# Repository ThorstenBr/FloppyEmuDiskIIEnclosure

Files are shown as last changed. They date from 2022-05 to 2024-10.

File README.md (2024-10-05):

# FloppyEmu Disk II Enclosure
This project contains OpenSCAD files, STL files, stickers and KiCad PCB to create a 3D-printed custom enclosure for the [Big Mess of Wires - FloppyEmu](https://www.bigmessowires.com/floppy-emu/) - an SD-card based disk drive emulator for the Apple II computer. The custom enclosure is a look-alike of the historic "Disk II" drive, Apple's first and hugely successful original disk drive for the Apple II, introduced in 1978.

As a bonus, this project also contains a housing for the Floppy Emu DB-19 plug adapter - a separate little 3D-print to protect the adapter (see "Bonus" section below).

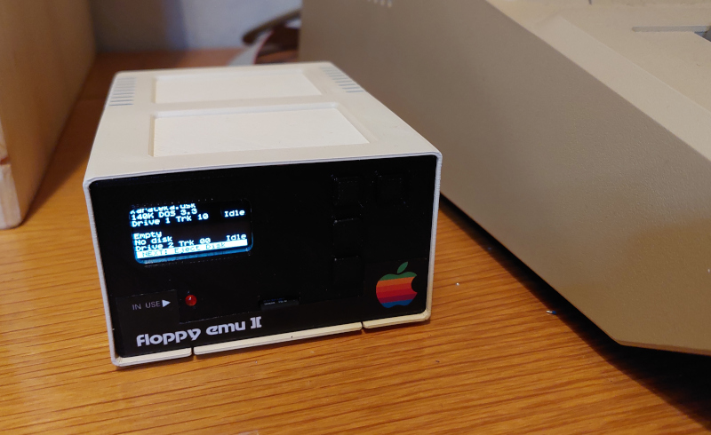
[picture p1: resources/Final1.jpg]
Final1

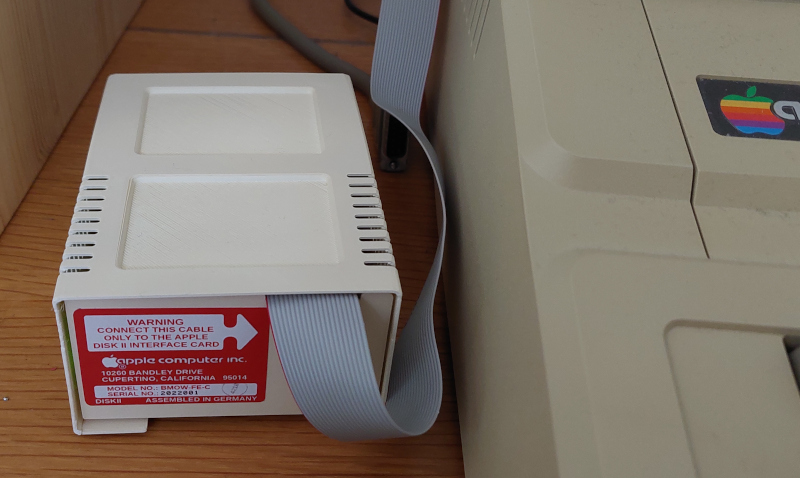
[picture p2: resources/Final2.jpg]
Final2


## Credits
The idea for this 3D-printing project was triggered by similar ideas to create Disk II-shaped custom enclosures for the FloppyEmu in the [AppleFritter](http://www.applefritter.com) forum - a forum for vintage Apple computer fans. See [this discussion thread](https://www.applefritter.com/content/yet-another-floppyemu-enclosure-3d-printing-approach) for more.

## License
This project is released under the "Creative Commons Attribution 4.0 International Public License". See [LICENSE](/LICENSE).

The Apple logo is a registered trademark of Apple Computer Inc. Any images and photos which may show the Disk II-FloppyEmu enclosure with an Apple logo were only given as an example of how you could decorate your Disk II-FloppyEmu drive enclosure for your personal use, to match the retro look of your wonderful original Apple II computer. The 3D-printed Disk II FloppyEmu enclosure is not endorsed by Apple. This project does not grant you any rights or licenses to distribute any 3D-printed enclosures with an Apple logo.

## Design
The 3D design is done with OpenSCAD. All files are available in the [scad](/scad/) folder.

The OpenSCAD file provides an option to generate the enclosure in different sizes. The minimum scale to fit the FloppyEmu PCB is 0.6 (= 60% of the original Disk II enclosure size). Currently, this reduced size is the only variant which is tested. The photos of the enclosure also show this reduced variant. Larger sizes will still require some tweaking in the SCAD files. The full-sized variant will be supported in the future (wait for it...).
You can also choose whether to use one LED (status LED only), or two LEDs (status + power LED). One LED is the default.

You can also find a ready-to-use STL files in the [stl](/stl/) folder. These STL files apply to the tested variant (60% of the original, one LED).

3D-Design2
3D-Design4
3D-Design3

## Button Panel
You will need a button panel, so you can control FloppyEmu from the front.
You can build the panel manually using a perfboard or order a printed circuit board (from JLCPCB etc).

The [pcb](/pcb/) folder contains all Gerber files required for a PCB order:

PCB
PCB

Alternatively, use a perfboard to solder the push buttons manually. It's only 4 buttons and a connector (and maybe the resistor for the status LED):

ButtonPanel1
ButtonPanel2

Schematics and the KiCad project for the PCB are also stored in [pcb](/pcb/) folder:

ButtonPanel4

PCB

The button PCB is eventually screwed to the front panel (Note: the photo does not show the latest design. The PCB is now mounted with 4 screws, one in each corner - see newer PCB design above).

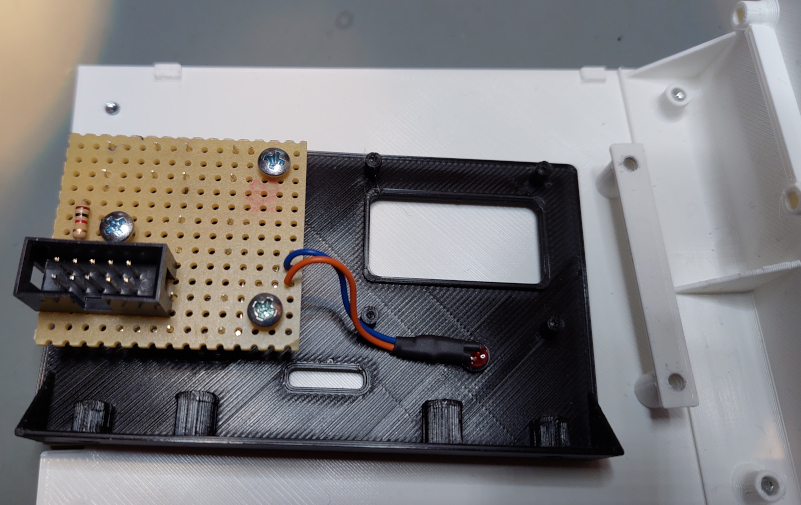
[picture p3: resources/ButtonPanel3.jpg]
ButtonPanel3


### Bill Of Materials

Here's what you need.

#### For the button panel:

- Manufactured PCB (i.e. upload the Gerber-Files to a PCB manufacturer, like JLCPCB). Alternatively use a [perfboard](https://en.wikipedia.org/wiki/Perfboard).
- 4x "micro switch push button 6x6x7mm" (ebay etc)
- 1x 3mm LED (red)
- 1x resistor (value depends on the type and intensity of your LED, usually 330 Ohm to 1KOhm)
- "2x5 box header" or, alternatively, "2x5 straight pin header"

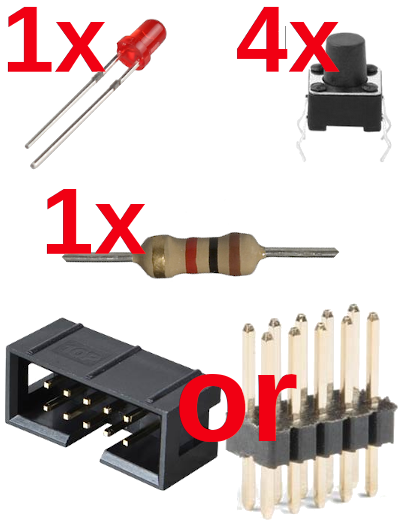
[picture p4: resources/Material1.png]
Material1


The four push buttons are very common and easy to obtain. They are similar as the onboard buttons of FloppyEmu. Except the PCB design is made for a through-hole type push buttons (not SMD buttons as on FloppyEmu). Switches with a 7mm peg are required to properly mount the printed button caps. Check on ebay searching for "micro switch push button 6x6x7mm". Your favourite electronics supplier should also have them (Germany: reichelt.de, TASTER 9303, Kurzhubtaster 6x6mm, 7,0mm).

#### For the button panel and LCD connector:
- You can use simple breadboard wires ("jumper wires") to connect FloppyEmu to the button panel and LCD. They are cheap and also come with a ribbon cable. The LCD and the button panel both require 7 wires each (since 3 pins of the button panel's pin header are unused).

- Alternatively, use "header plugs" with matching ribbon cable (2x5 for the button panel, 2x8 for the LCD) - as shown in the build photos. This is a slightly more expensive and complex solution. 

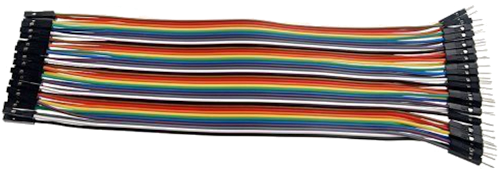
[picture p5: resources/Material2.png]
Material2


## Wiring FloppyEmu
The FloppyEmu PCB does not provide convenient pins or solder pads to tap the button and LED status signals. However, it's still relatively easy to tap the required signals - as shown by these photos. The photos apply to the Revision C model of the BMOW FloppyEmu. For other revisions, better verify the wiring with a multimeter.

A single wire is enough for each push button is enough: all four push buttons, including the reset button, connect to common ground. The status LED, however, does not connect to ground: it's wired between the status output signal and +5V (via an appropriate resistor for the LED, of course). The only feasible place is to solder directly next to the LED. The status signal is on the right of the LED – as shown. Be careful when soldering – just touch the LED very briefly with the iron – otherwise the onboard LED will die.

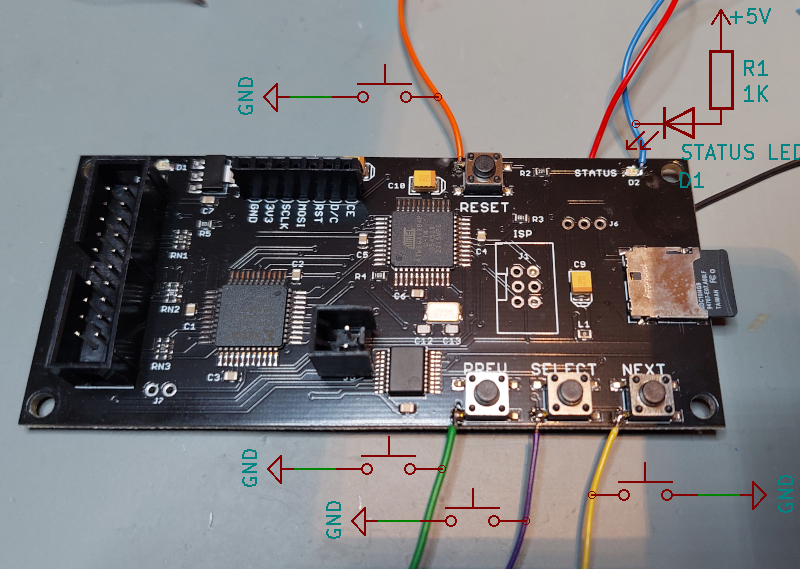
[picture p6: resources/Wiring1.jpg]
Wiring1


You can wire the ground lead (common for all push buttons) and the 5V (for the status LED) to the unpopulated debug connector in the middle of the FloppyEmu PCB. I soldered these two on the PCB’s bottom side, so they are almost “invisible” once the PCB is installed.

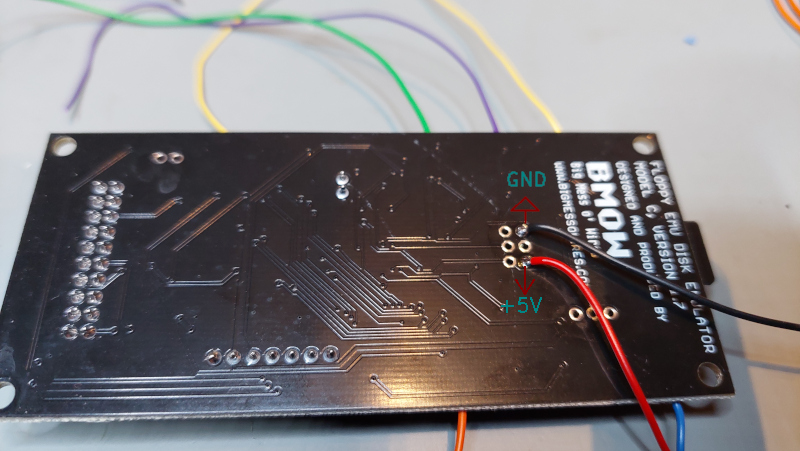
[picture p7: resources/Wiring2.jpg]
Wiring2


I suggest you solder all wires to a 2x5 pin header (or boxed header), so you can use a neat ribbon cable with plugs to connect the front button panel. The ribbon cable connects all four button signals, the status signal, ground and 5V – so three pins remain unused. If you wanted a power LED – just connect between ground and 5V (via a resistor, of course). See the schematics in the [pcb](/pcb) folder for a suggested pin assignment of the pin header/ribbon cable.

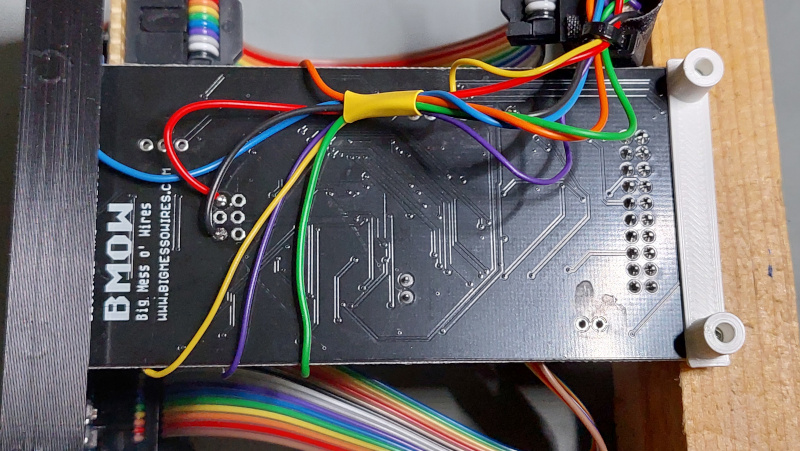
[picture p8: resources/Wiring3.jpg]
Wiring3


## 3D Print
3D printing is straight forward. The models should be printed with their flat side facing downwards.

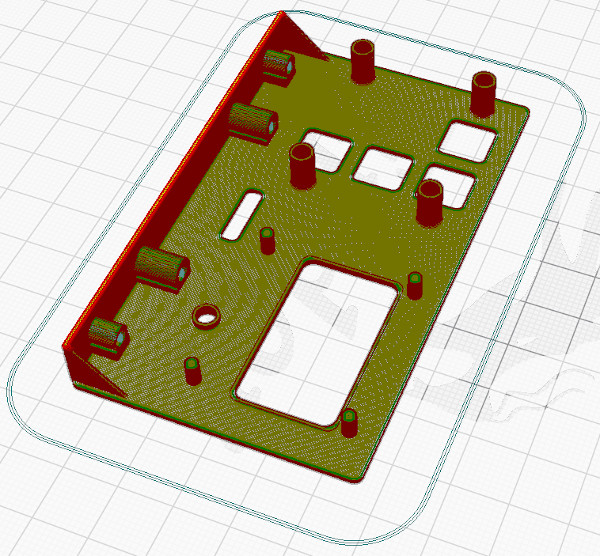
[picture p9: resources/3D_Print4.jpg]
3DPrint4


Preferably use white or light gray filament for the top shell, base plate, and for the rear panel. Use black filament for the front panel and the buttons.

The models are optimized to reduce 3D "supports", however, the top shell and the front panel still need "supports" to be enabled when printing.

The buttons should be printed without supports. Two brackets are also printed: a bracket for the PCB (feet to tbe attached to the PCB rear). And a bracket for the cable strain-relief (cable can be attached to a mount at the top/rear of the shell).

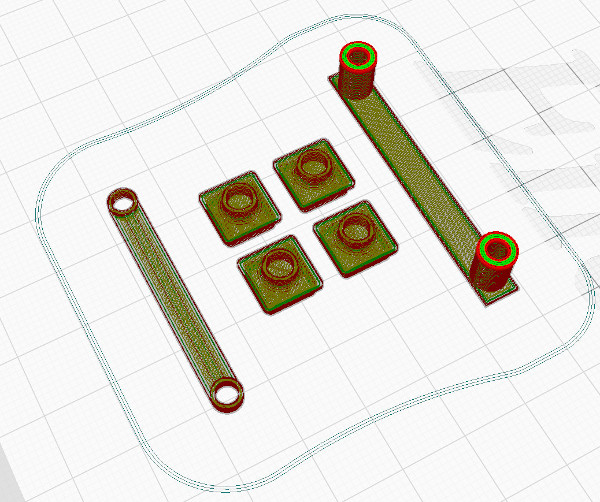
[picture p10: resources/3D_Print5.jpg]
3DPrint5


The large grooves on the top shell do require supports though - since this model should be printed upside down:

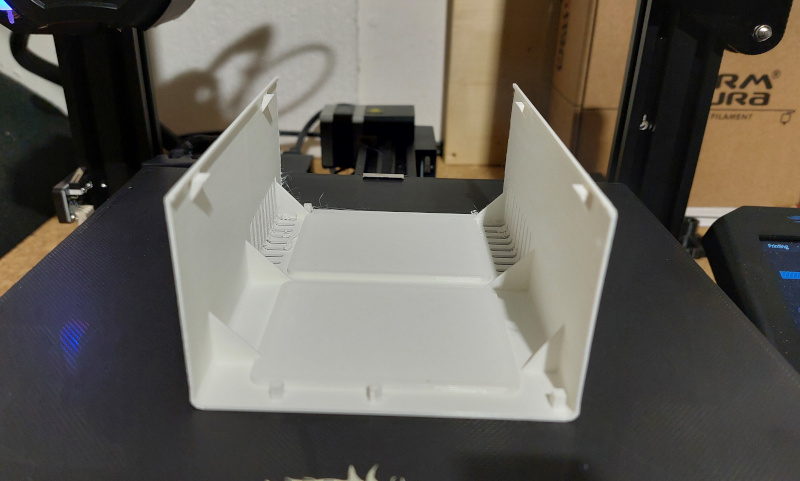
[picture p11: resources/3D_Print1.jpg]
3DPrint1


Carefully remove the printed "supports" to reveal the top grooves:

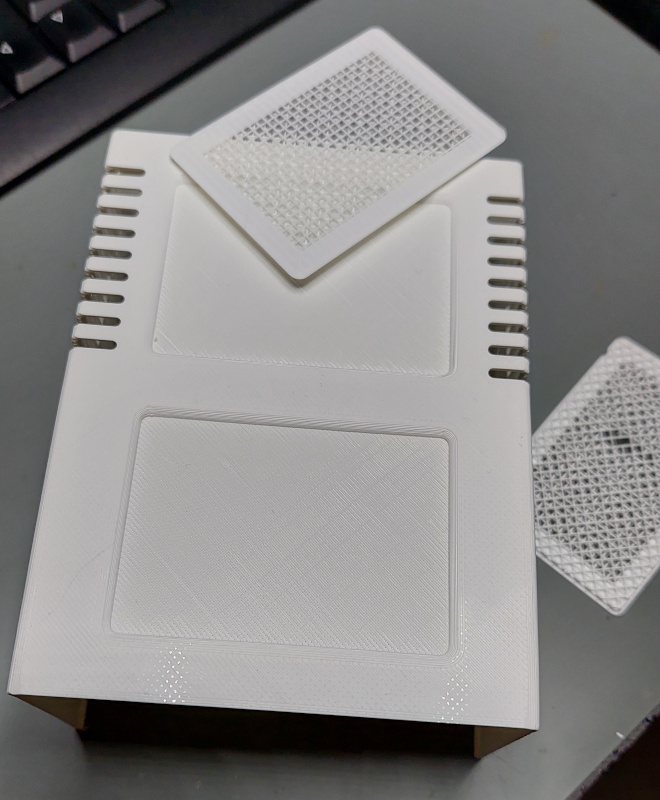
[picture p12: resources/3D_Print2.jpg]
3DPrint2


### Print Duration
The top shell takes about 7 hours to print on an Ender 3v2.
The front and rear panel require about 1:30 hours.
The buttons and mounting brackets require about 30 minutes.

## Assembly

### Shell
The top shell and the base plate should be glued together. Make sure to completely cover the seam between these two elements, since these two parts were split for easier 3D printing, and the original Disk II does have different seams. Smoothing these seams (before applying beige "Apple II"-like paint - I used spray-paint) comepletely hides the seam. Glueing these two parts also provides extra strength: there should be no more wobble or flexing once the two parts are glued.

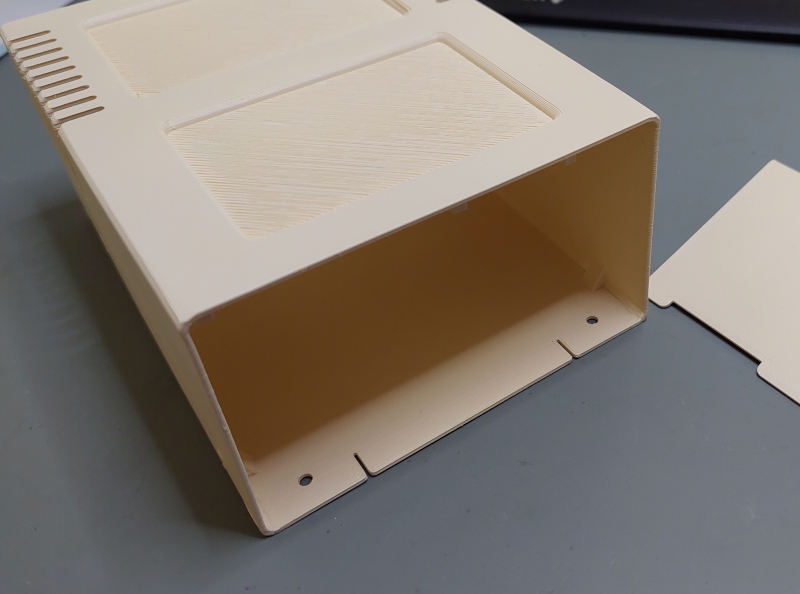
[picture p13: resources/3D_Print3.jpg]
3DPrint3


### Front Panel
First, the PCB is directly attached to the front panel with two screws.
The rear of the PCB is screwed to the printed mounting bracket ("PCB feet").
Then, attach the button PCB (perfboard of printed circuit board) with four screws to the front panel.
Make sure the four buttons are working fine
The push buttons only travel 0.25mm when depressed.
If the PCB was slightly warped or the buttons are soldered unevenly, slightly adjust the distance between the PCB and the front-panel.
Just unscrewing one of the four screws to release a bit of pressure may already be enough.

The LCD display is clipped into the front panel. The pegs should exactly fit to the original FloppyEmu LCD.
If necessary, use glue to prevent the LCD from slipping from the little pegs (this should normally not be necessary though, if you do not clip and remove the LCD from the front panel too often).

Use a ribbon cable to connect the LCD to the original connector on the FloppyEmu PCB (make sure to connect the cable with the correct orientation!).
Depending on the connector plugs, you may need to slightly bend the pins on the LCD, so they are angled 10-20° downward (may be necessary if the plug is too high and touches the top of the shell).

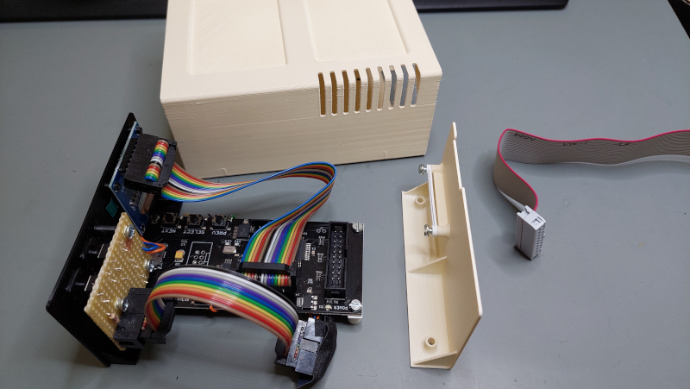
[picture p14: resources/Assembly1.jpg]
Assembly1


Eventually, when everything is connected, the whole assembly slides into the front of the 3D-printed shell.

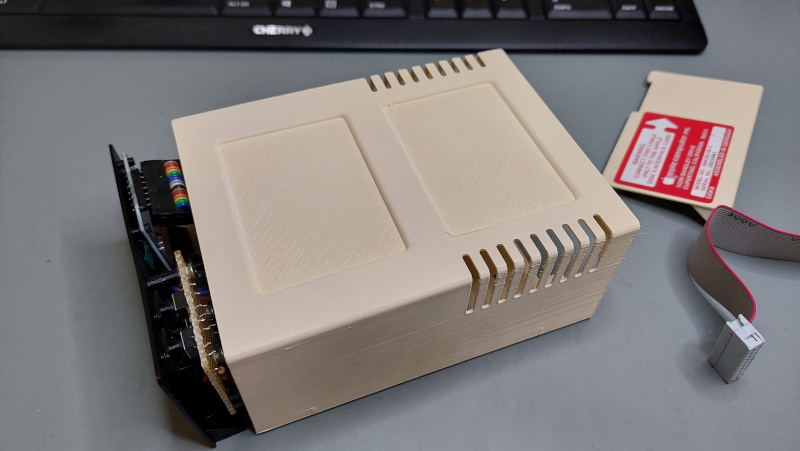
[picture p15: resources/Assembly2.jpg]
Assembly2


The front panel and the rear-bracket of the PCB are fixed to the base plate with screws from the bottom of the shell.

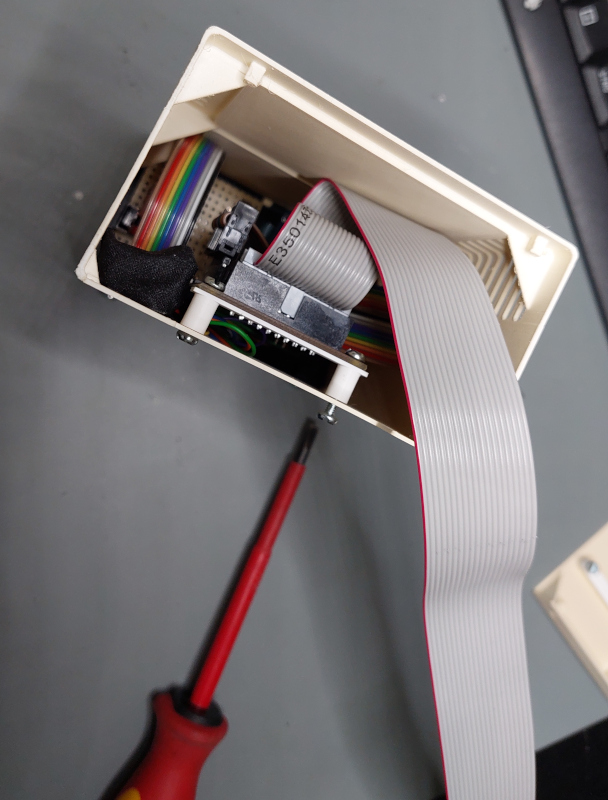
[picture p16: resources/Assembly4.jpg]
Assembly4


Once the PCB/front-panel is installed, connect the disk drive ribbon cable and use the printed cable bracket to attach the cable to the cable strain-relief at the top of the shell. This also guides the cable towards the cable slot in the rear-panel (photos above do not quite match: the cable strain-relief has since moved from the rear panel to the top of the shell).

Finally attach the rear panel with two screws from the bottom.

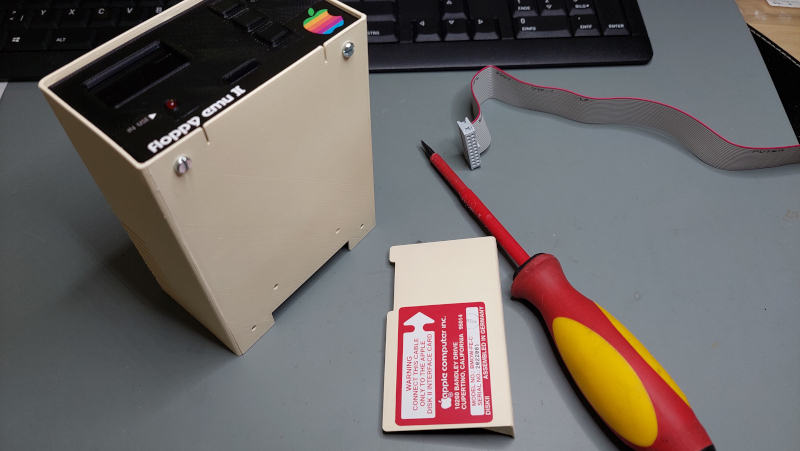
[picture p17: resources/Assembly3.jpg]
Assembly3


Almost done!

But remember: it's not complete... without rubber feet... :)

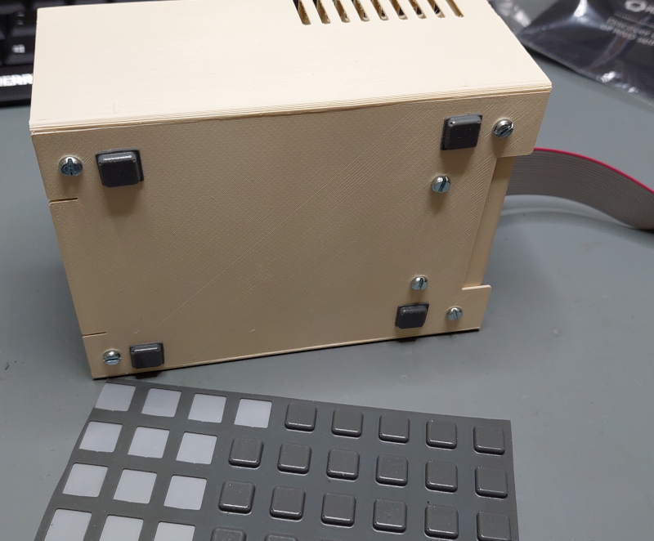
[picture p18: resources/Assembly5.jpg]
Assembly5


Done! :)

## Stickers
By the way, check the [sticker](/sticker/) folder for a collection of stickers to decorate your device.
Several variants of the rear sticker are provided.
The designs are also available as GIMP image files (.xcf), so you can adapt the text to your needs.

The stickers are now also available in high quality [here](/sticker/HighQuality). Many thanks to [khaibitgfx](https://www.applefritter.com/khaibitgfx)!

## Bonus: Floppy Emu DB-19 adapter housing

The Floppy Emu DB-19 adapter is provided as a bare PCB only. It is usually connected to the back of your Apple II and rarely touched. However, you should still be careful with the adapter since the pins carry the +5V rail and also the +/- 12V rails. Since Disk II cable has the +/-12V rails connected to pins which are directly next to disk control and read/write signals (TTL/5V logic). A shortcut between these pins could easily damage the disk controller, the Apple II, or FloppyEmu (or all of them):

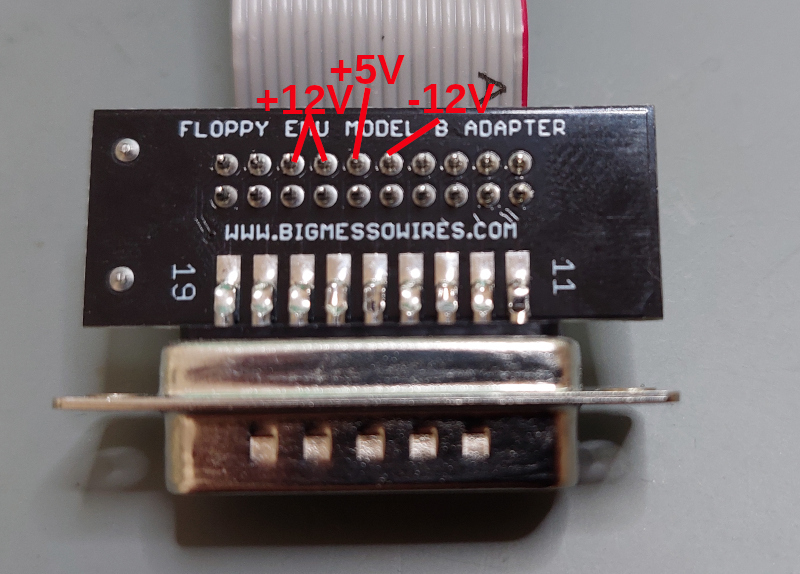
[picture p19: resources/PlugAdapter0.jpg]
PlugAdapter0


The 3D-printed plug adapter housing provides proper protection for the adapter. The adapter PCB slides right into the bottom part of the housing:

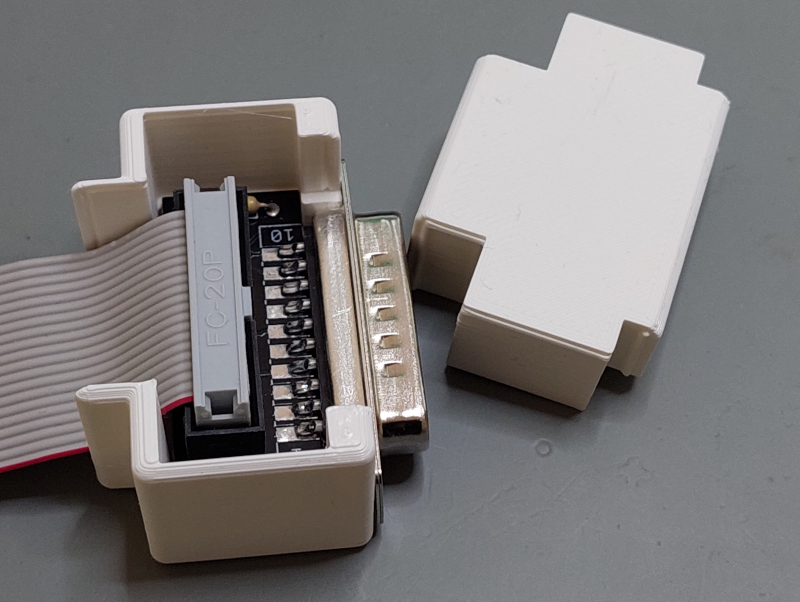
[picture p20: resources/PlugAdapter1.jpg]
PlugAdapter1


The top is printed with some notches, so it snaps right into place - and firmly holds the adapter PCB/plug:

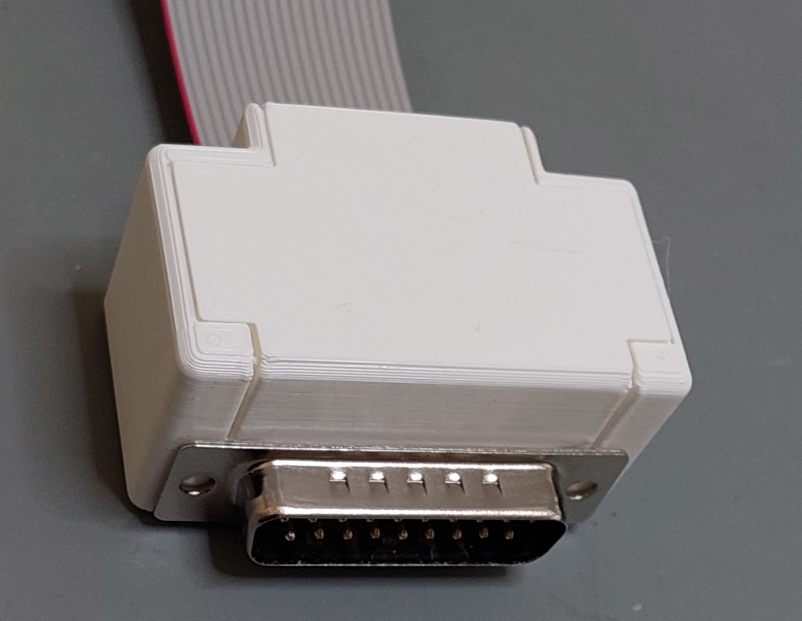
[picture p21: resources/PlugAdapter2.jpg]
PlugAdapter2

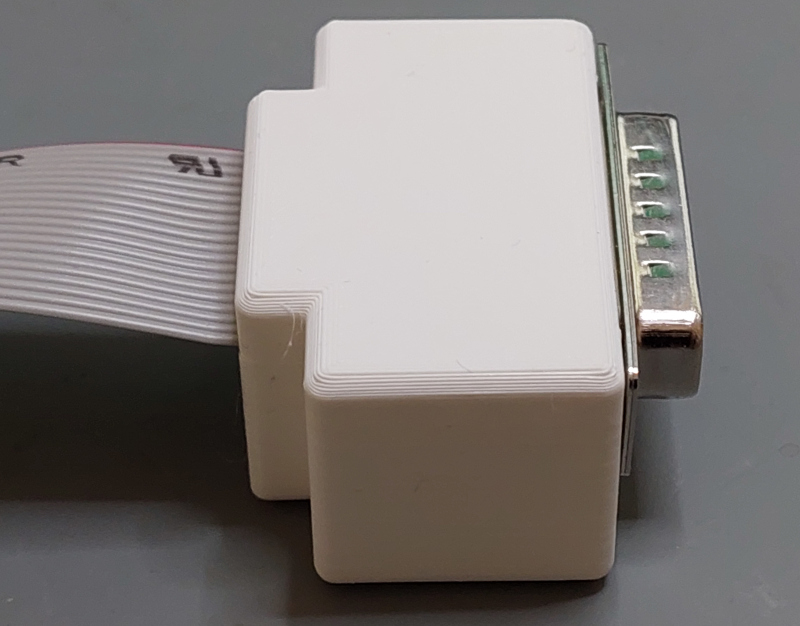
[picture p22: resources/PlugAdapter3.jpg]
PlugAdapter3


The result is a fairly bulky plug, but that's due to the clunky nature of the "_PCB-box header-header plug-ribbon cable_" assembly.

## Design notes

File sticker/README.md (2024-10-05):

These stickers are only provided as an example, of how you could decorate your 3D-printed enclosure.
You can adapt the stickers with GIMP, using the original XCF files, which allow to edit and adapt the text.

Also see the new high quality variant of the stickers [here](/sticker/HighQuality).

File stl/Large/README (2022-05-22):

This folder contains the full-sized variant of the FloppyEmu Disk II enclosure. It's at 1:1 scale of the original Disk II.
The full-sized box should be used with a 5mm LED and a custom 2.42" LCD display (128x64 pixels, SSD1309).
If you want to use the original 1.7" LCD of FloppyEmu then it's recommended to use the small (60%) box.

TBD: The 1:1 scaled design is currently untested. Hence, STL files are not yet provided. You could still generate the
full-scaled STL by using the SCAD files (OpenSCAD). However, the full-scaled variant of the design will most certainly
still require tweaking. Otherwise come back in a few months or so, to check on the status of the full-scaled variant...

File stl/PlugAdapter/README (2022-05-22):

Housing for Floppy Emu's DB-19 plug adapter.

Hints for printing:
* The models should be printed with their flat side facing downwards.
* Prints without supports.
* There are some bulky volumes to firmly hold the plug. I used Cura's stock infill setting (20%).
* The design printed fine with an Ender 3v2 printer, sliced with Ultimaker Cura using stock settings.
* Priting duration is about 2:10 hours (with Ender 3v2).

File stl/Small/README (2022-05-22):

This folder contains the small sized variant of the FloppyEmu Disk II enclosure. It's 60% of the size of the original Disk II.
It's just big enough to hold the FloppyEmu PCB.
The front panel holds the FloppyEmu's orginal 1.7" LCD, a single 3mm LED (drive status) and the button panel.

Hints for printing:
* The models should be printed with their flat side facing downwards.
* Preferably use white or light gray filament for the top shell, base plate, and for the rear panel.
* Use black filament for the front panel and the buttons.
* The models are optimized to reduce 3D "supports", however, the top shell and the front panel still need "supports" to be enabled when printing.
* The buttons/brackets and base-plate print without "supports".
* The infill setting doesn't matter (design does not contain any large filled volumes).
* The design printed fine with an Ender 3v2 printer, sliced with Ultimaker Cura using stock settings.

Printing Duration (estimates for an Ender 3v2):
* Top shell: about 7 hours.
* Front and rear panel: about 1:30 hours.
* Buttons and mounting brackets: about 30 minutes.

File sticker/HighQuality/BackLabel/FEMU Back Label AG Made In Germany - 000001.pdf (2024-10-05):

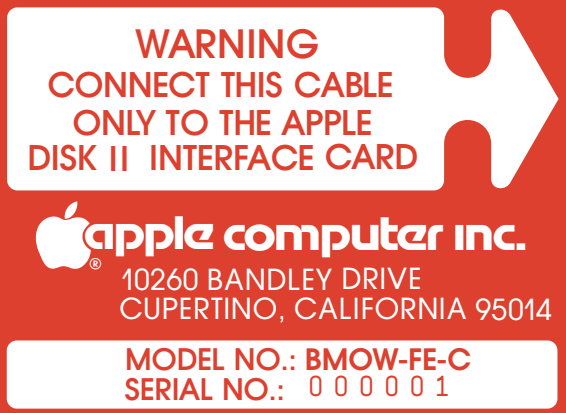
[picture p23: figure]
WARNING CABLE; ONLY DISK II; BANDLEY DRIVE CUPERTINO, CALIFORNIA; MODEL NO.: BMOW-FE-C SERIAL; CONNECT THIS TO THE APPLE INTERFACE CARD; apple computer inc.

MADE IN GERMANY

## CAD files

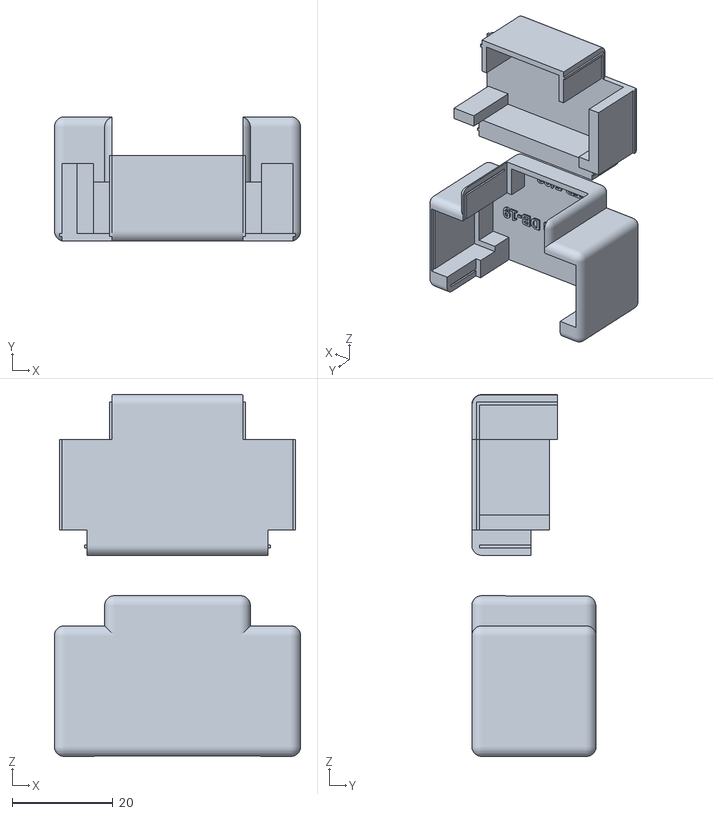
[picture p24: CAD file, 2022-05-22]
stl/PlugAdapter/plug_adapter.stl
49.0 x 24.8 x 72.0

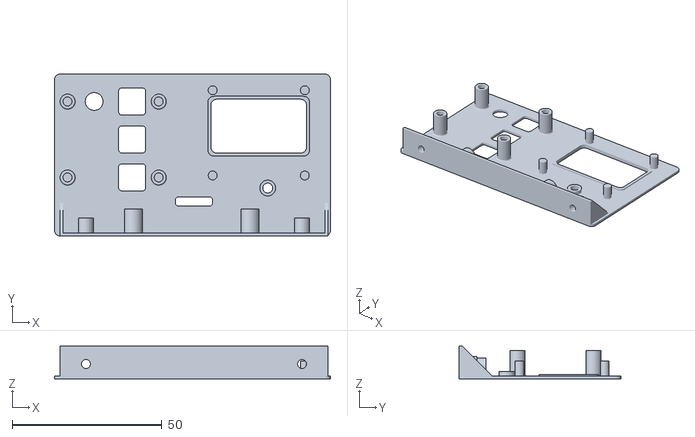
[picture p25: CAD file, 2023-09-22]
stl/Small/DiskII_FrontPanel_Small.stl
92.3 x 54.1 x 11.0

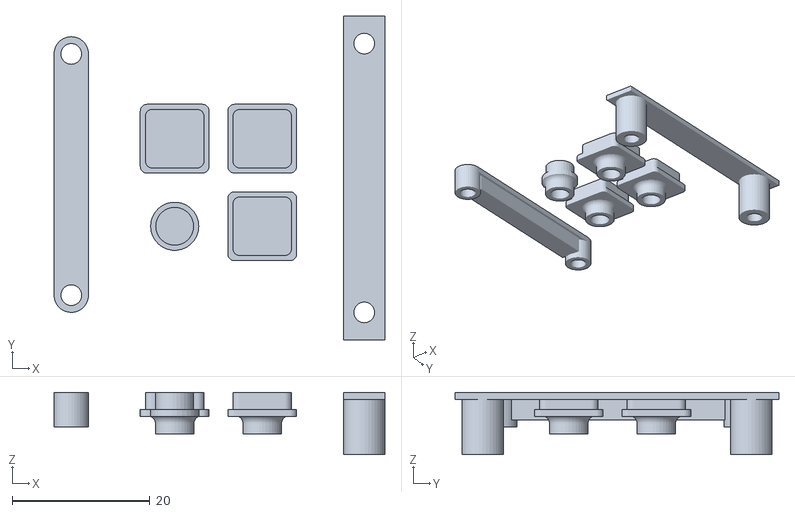
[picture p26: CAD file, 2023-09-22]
stl/Small/DiskII_ButtonsBrackets_Small.stl
48.0 x 47.0 x 9.00

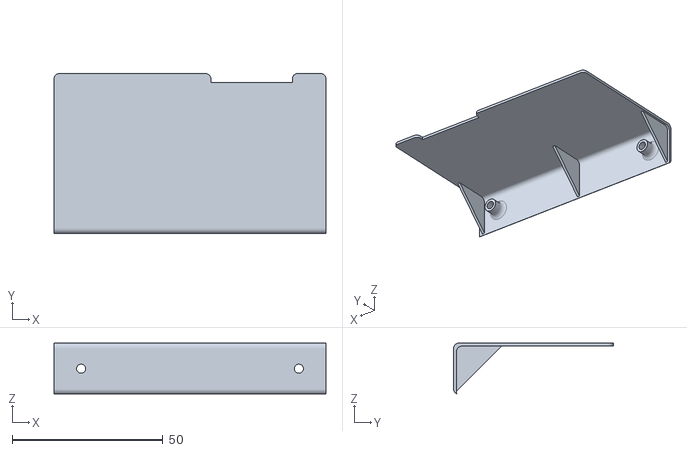
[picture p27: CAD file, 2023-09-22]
stl/Small/DiskII_RearPanel_Small.stl
90.3 x 53.1 x 16.9

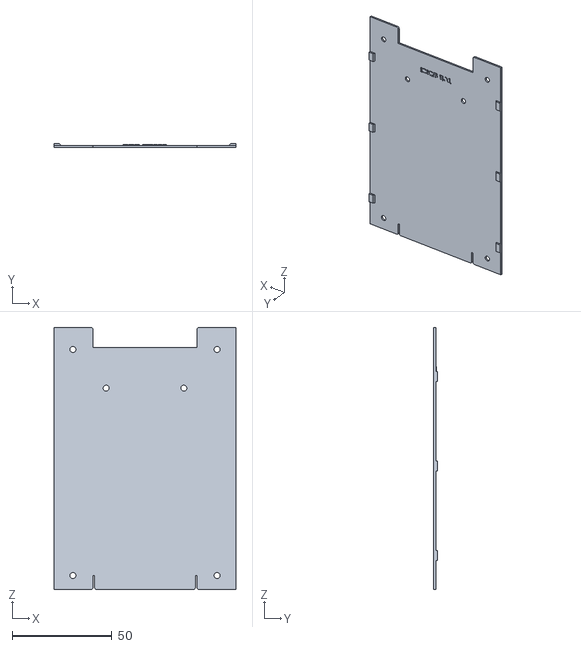
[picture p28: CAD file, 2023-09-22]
stl/Small/DiskII_BasePlate_Small.stl
91.2 x 2.00 x 131.4

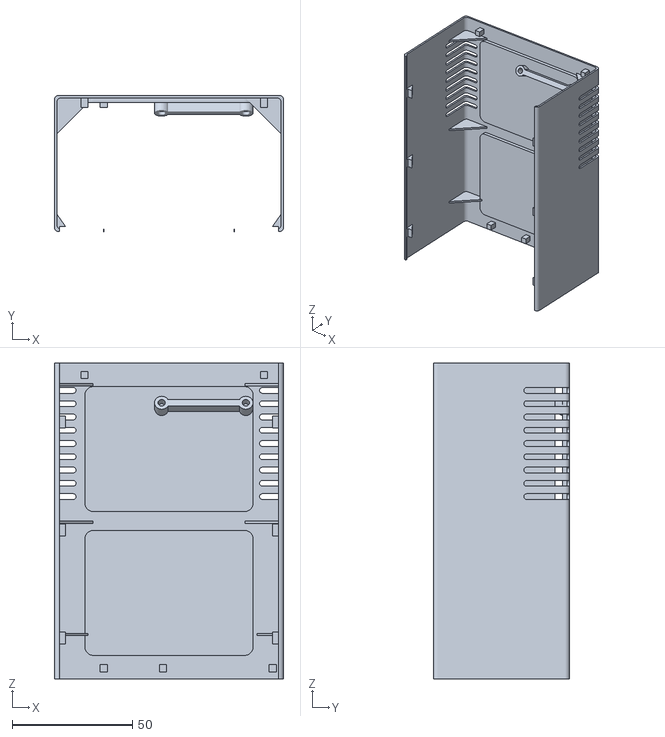
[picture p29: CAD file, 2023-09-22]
stl/Small/DiskII_TopShell_Small.stl
95.3 x 56.6 x 131.4

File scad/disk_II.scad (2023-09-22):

// Copyright 2022 Thorsten Brehm
// brehmt (at) gmail dot com

// Which part do you want to see/generate?
PART = "bottom"; // [button:Buttons and Brackets, bottom:Base board element, top:Top shell, rear:Rear panel, front:Front panel, test:--Test--, all:All elements, noRear:All except the rear panel, noFront:All except front panel, noBottom: All except base board, frontBottom: Front and base board only, topBottom: Top shell and base board only]

// Size of the LCD display?
LCD = "small"; // [small:Original 1.7inch display, large:Jumbo 2.42inch display]

// show FloppyEmu PCB?
PCB = "no"; // [no:No,yes:Yes]

// Size of the box: 1.0=original Disk II drive size, 0.6='baby box', just matching floppy EMU size
SCALING = 0.6; // [0.1 : 0.01 : 1]

// Which/how many LEDs?
LEDs = "one"; // [one:One / Activity LED,two:Both / Activity and Power LEDs]

/* [Internals] */
// Base board imprint
IMPRINT = "TCB 9/2023";  // 30

// Distance of the components (when showing 'exploded' elements)
SEPARATION = 30; // [0: 1: 100]

// Add cable strain-relief to top shell
STRAIN_RELIEF = "yes"; // [no:No,yes:Yes]

/* [Hidden] */
// Use prototype cutouts to save filament?
prototype = "no"; // [no:No,yes:Yes]

// Add 3D print supports
supports = "yes"; // [no:No,yes:Yes]

showPcb = PCB;
part = PART;
ComponentSeparation = SEPARATION;
ScalingFactor = SCALING;
LedCount = (LEDs == "two") ? 2 : 1;

include <components/main.scad>

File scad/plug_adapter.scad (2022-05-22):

// Copyright 2022 Thorsten Brehm
// brehmt (at) gmail dot com

// Enclosure for the Floppy Emu DB-19 Plug Adapter

// Which part do you want to see/generate?
PART = "topBottom"; // [topBottom: Both elements, bottom:Bottom element, top:Top element, test:--Test--, full:Full, mask:Show top mask, pcb:Show PCB, carving:Carved space]

/* [Hidden] */

// Adapter PCB
PcbWidthX = 46;
PcbHeightY = 2;
PcbDepthZ = 18;

// Box Header
BoxHeaderWidthX = 33.5;
BoxHeaderHeightY = 14;
BoxHeaderDepthZ = 11.5;

BoxHeaderPositonZ = PcbDepthZ-BoxHeaderDepthZ; // position from the front of the PCB

BoxHeaderPinHeightY = 2; // height of the pins on the PCB bottom side

// Cable
CableWidthX = 26;
CableHeightY = 1.0; // 1.5

CablePositionY = -CableHeightY/2;

// SUB-D Connector
SubDWidthX = 33;
SubDHeightY = 11.5;
SubDDepthZ = 13;

SubDPlateWidthX = 45;
SubDPlateHeightY = 13;
SubDPlateDepthZ = 1;

SubDPlatePositonZ = 5; // position from the front of the PCB

// rear
RearDepthZ = 6;

SKIN = 1.5;

SnapNotchX = 0.5;
SnapNotchY = 0.6;

// quality setting
QUALITY = "high";

include <components/baseLib.scad>

module imprint(x,y,z, txt, Font = "Liberation Sans:style=Bold")
{
	FontSize = 3;
	translate([x,y,z])
	rotate([270,0,0])
	{
		linear_extrude(height = 0.4) { text(txt, font = Font, size = FontSize, halign="center", valign="center"); }
	}
}

module makeFilamentSaver()
{
	translate([-BoxHeaderWidthX/2,0,0]) cube([BoxHeaderWidthX, PcbHeightY+BoxHeaderHeightY, BoxHeaderPositonZ]);
	translate([-PcbWidthX/2, PcbHeightY, SKIN*2]) cube([PcbWidthX-2*SKIN, BoxHeaderHeightY, PcbDepthZ-SKIN*2]);

	// cable
	translate([-(CableWidthX-2*SKIN)/2, -SubDHeightY/2, 0])
		cube([CableWidthX-2*SKIN, PcbHeightY+BoxHeaderHeightY+SubDHeightY/2, BoxHeaderPositonZ+BoxHeaderDepthZ+RearDepthZ+SKIN]);

	// Box header pins (below PCB)
	translate([-(PcbWidthX-2*SKIN)/2, -SubDHeightY/2, SKIN]) cube([PcbWidthX-2*SKIN, SubDHeightY/2, BoxHeaderDepthZ+BoxHeaderPositonZ-SKIN]);
}

module makePcb()
{
	// PCB
	translate([-PcbWidthX/2,0,0]) cube([PcbWidthX, PcbHeightY, PcbDepthZ]);

	// Box Header
	translate([-BoxHeaderWidthX/2, PcbHeightY, BoxHeaderPositonZ]) cube([BoxHeaderWidthX, BoxHeaderHeightY, BoxHeaderDepthZ]);

	// Box header pins (below PCB)
	translate([-BoxHeaderWidthX/2, -BoxHeaderPinHeightY, BoxHeaderPositonZ]) cube([BoxHeaderWidthX, BoxHeaderPinHeightY, BoxHeaderDepthZ]);

	// SUB-D connecor
	translate([-SubDWidthX/2, -SubDHeightY/2, -SubDDepthZ]) cube([SubDWidthX, SubDHeightY, SubDDepthZ+SKIN]);
	// SUB-D connector plate
	translate([-SubDPlateWidthX/2, -SubDPlateHeightY/2, -SubDPlatePositonZ-SubDPlateDepthZ]) cube([SubDPlateWidthX, SubDPlateHeightY, SubDPlateDepthZ]);

	// cable
	translate([-CableWidthX/2, CablePositionY, BoxHeaderPositonZ+BoxHeaderDepthZ]) cube([CableWidthX, CableHeightY, 20]);
}

module makeBlock()
{
	translate([-SKIN-PcbWidthX/2, -SKIN-SubDHeightY/2, -SubDPlatePositonZ])
		rcube(size=[2*SKIN + PcbWidthX, 2*SKIN + SubDHeightY/2+PcbHeightY+BoxHeaderHeightY, SKIN*2 + PcbDepthZ+SubDPlatePositonZ],
	              radius=[2,2,2], center=false);

	translate([-SKIN-CableWidthX/2, -SKIN-SubDHeightY/2, PcbDepthZ-1])
		rcube(size=[2*SKIN + CableWidthX, 2*SKIN + SubDHeightY/2+PcbHeightY+BoxHeaderHeightY, SKIN*2 +RearDepthZ+1],
	              radius=[2,2,2], center=false);
}

module makeThing()
{
	difference()
	{
		makeBlock();
		union()
		{
			makePcb();
			makeFilamentSaver();
		}
	}
	imprint(0, -SubDHeightY/2, PcbDepthZ/2, "Floppy Emu DB-19");
	imprint(0, -SubDHeightY/2, PcbDepthZ+RearDepthZ/2+SKIN, "TB 5/22");
}

module makeTopMask()
{
	// cable
	translate([-CableWidthX/2, CablePositionY+CableHeightY, BoxHeaderPositonZ+BoxHeaderDepthZ])
		cube([CableWidthX, SKIN+BoxHeaderHeightY-CablePositionY+PcbHeightY-CableHeightY, 20]);

	// PCB area
	translate([-PcbWidthX/2, PcbHeightY, 0])
		cube([PcbWidthX, SKIN+BoxHeaderHeightY, PcbDepthZ]);

	// subd
	translate([-(SubDWidthX+2*SKIN)/2, SubDHeightY/2, -SubDDepthZ])
		cube([SubDWidthX+2*SKIN, SKIN+PcbHeightY+BoxHeaderHeightY-SubDHeightY/2, SubDDepthZ]);

	// click notch (cable)
	translate([-CableWidthX/2-SnapNotchX, BoxHeaderHeightY+SKIN+0.5, PcbDepthZ])
		cube([CableWidthX+SnapNotchX*2, SnapNotchY, RearDepthZ+SKIN]);
	translate([-CableWidthX/2-SnapNotchX, CablePositionY+CableHeightY, PcbDepthZ+RearDepthZ+SKIN/2+0.15])
		cube([CableWidthX+SnapNotchX*2, BoxHeaderHeightY-CablePositionY+PcbHeightY-SKIN+0.5, SnapNotchY]);

	// click notch (PCB)
	translate([-PcbWidthX/2-SnapNotchX, BoxHeaderHeightY+SKIN+0.5, 0])
		cube([PcbWidthX+SnapNotchX*2, SnapNotchY, PcbDepthZ]);

	// click notch (subd)
	translate([-(SubDWidthX+2*SKIN+SnapNotchX*2)/2, SubDHeightY/2, -SubDPlatePositonZ+SKIN])
		cube([SubDWidthX+2*SKIN+SnapNotchX*2, PcbHeightY+BoxHeaderHeightY-SubDHeightY/2, SnapNotchY]);

}

module makeTop()
{
	intersection()
	{
		makeThing();
		makeTopMask();
	}
}

module makeBottom()
{
	difference()
	{
		makeThing();
		makeTopMask();
	}
}

module main()
{
	if (PART == "test")
	{
	}
	else
	if (PART == "top")
	{
		makeTop();
	}
	else
	if (PART == "bottom")
	{
		makeBottom();
	}
	else
	if (PART == "full") {
                 makeThing();
	}
	else
	if (PART == "mask")
	{
		makeTopMask();
	}
	else
	if (PART == "topBottom")
	{
		translate([0, PcbHeightY+BoxHeaderHeightY+SKIN, 40]) rotate([180,180,0]) makeTop();
		translate([0, SKIN+SubDHeightY/2, 0]) makeBottom();
	}
	else
	if (PART == "carving")
	{
		makePcb();
		makeFilamentSaver();
	}
	else
	if (PART == "pcb") {
		makePcb();
	}
	else
	{
		// nothing!
	}
}

main();

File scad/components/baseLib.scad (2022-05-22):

// Copyright 2022 Thorsten Brehm
// brehmt (at) gmail dot com

module torus(r1, r2)
{
    rotate_extrude(convexity = 10)
		translate([r2 + r1, 0, 0])
			circle(r=r2);
}

module round_cylinder(fillet, r, h)
{
	for(z=[fillet, h-fillet])
		torus(r-2*fillet, fillet, center=[0,0,z]);
	cylinder(r=r-fillet, h);
	translate([0,0,fillet]) cylinder(r=r, h=h-2*fillet);
}

// Make a rectangle with rounded corners of given radius.
// The maximum outer dimensions exactly match the given width/height.
module roundedCube(Width, Height, Depth, CornerRadius)
{
	$fn=36;
	union()
	{
		for (x=[0,Width-CornerRadius*2])
		for (y=[0,Height-CornerRadius*2])
			translate([x+CornerRadius, y+CornerRadius, 0]) cylinder(r=CornerRadius, h=Depth);
		translate([CornerRadius,0,0]) cube([Width - 2*CornerRadius, Height, Depth]);
		translate([0,CornerRadius,0]) cube([Width, Height - 2*CornerRadius, Depth]);
	}
}

module cylinderLedge(r, length)
{
	$fn=36;
	translate([0, 0, -length/2])
	intersection()
	{
		cylinder(r=r, length);
		cube([r, r, length]);
	}
}

module rcube(size=[30, 20, 10], radius=[3, 2, 1], center=true)
{
	hull() {
        translate( center ? [0,0,0] : size/2 ) {
            cube(size-2*radius+[2*radius[0],0,0],center=true);
            cube(size-2*radius+[0,2*radius[1],0],center=true);
            cube(size-2*radius+[0,0,2*radius[2]],center=true);
 
            for(x = [-0.5,0.5], y = [-0.5,0.5], z = [-0.5,0.5])
                translate([x * ( size[0] - 2*radius[0]),
                           y * ( size[1] - 2*radius[1]),
                           z * ( size[2] - 2*radius[2])])
                    scale([radius[0], radius[1], radius[2]])
                        if (QUALITY == "high") sphere(1.0,$fn=4*4*2); else sphere(1.0,$fn=4);
        }
    }
}

module hole(diameter, depth)
{
	$fn = 36;
	cylinder(r=diameter/2, h=depth);
}

module wall(width, height, WallThickness)
{
        translate([-width/2,-WallThickness/2,-height]) cube([width, WallThickness, height]);
}

module prism(l, w, h)
{
	polyhedron(
               points=[[0,0,0], [l,0,0], [l,w,0], [0,w,0], [0,w,h], [l,w,h]],
               faces=[[0,1,2,3],[5,4,3,2],[0,4,5,1],[0,3,4],[5,2,1]]
               );
}
	   
module post(height, diameter, post_fillet_r, screw_hole_diameter, screw_hole_depth)
{
	$fn = 36;
    difference() {
      union() {
        cylinder(r=diameter/2, h=height);
        difference() {
                cylinder(r=diameter/2 + post_fillet_r, h=post_fillet_r);
                translate([0,0,post_fillet_r]) torus(diameter/2, post_fillet_r*1.1);
        }
      }
      if (screw_hole_diameter>0)
      {
          translate([0,0,height-screw_hole_depth])
          hole(screw_hole_diameter, screw_hole_depth);
      }
    }
}

module screwPost(ZDepth, PostDiameter, ScrewDiameter, ScrewHoleDepth, FilletR)
{
    if (PostDiameter>0.0)
	post(ZDepth, PostDiameter, FilletR, ScrewDiameter, ScrewHoleDepth);
}


module outerBox(SkinWidth, XWidth, YHeight, ZDepth, CornerRadius)
{
	translate([-SkinWidth, -SkinWidth, 0]) roundedCube(XWidth+SkinWidth*2, YHeight+SkinWidth*2, ZDepth, CornerRadius);
}

module box(SkinWidth, XWidth, YHeight, ZDepth, CornerRadius)
{
	// main shell
	difference() {
		outerBox(SkinWidth, XWidth, YHeight, ZDepth, CornerRadius);
			//rcube(size=[XWidth+SkinWidth*2, YHeight+SkinWidth*2, ZDepth+SkinWidth*2], radius=[2, 2, 2], center=false);
		if (SkinWidth>0)
			roundedCube(XWidth, YHeight, ZDepth, CornerRadius);
			//rcube(size=[XWidth, YHeight, ZDepth], radius=[2, 2, 2], center=false);
	}
}

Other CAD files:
scad/components/buttons.scad
scad/components/front.scad
scad/components/main.scad
scad/components/pcb.scad
scad/components/rear.scad
scad/components/top_and_bottom.scad

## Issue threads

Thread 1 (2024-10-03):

Support settings?

k6lcm, 2024-10-03:
Wondering how you were able to get such clean support removal for the indents in the top. In Cura using PETG on my Neptune 4 Plus, my "normal" supports are frozen in place and trees make for a sloppy finish. I tried enabling "support interfaces" but that didn't help. Any tips for slicer settings to get the results shown in the photo?

Great project, BTW!

k6lcm, 2024-10-03:
I also tried in PLA but experienced the same issue.

ThorstenBr, 2024-10-03:
Thanks! :) I didn't do anything special: I printed with PLA (Verbatim) with standard settings (with Cura, printing on an Ender3v2).

You can see how the supports looked like in this photo, with the regular mesh. Also, the support on the right shows some tell tale signs, how I removed it: I jammed a screw driver in between the layers of the support mesh, somewhere in the middle. I pushed the screw driver in almost horizontally, so not to scratch the part it self, until I could apply enough lifting force. Then it popped right off. That had worked really well for me every time.

https://github.com/ThorstenBr/FloppyEmuDiskIIEnclosure/blob/main/resources/3D_Print2.jpg

k6lcm, 2024-10-03:
Ok. I'll mess with some settings on my Neptune 4 and report back. I know supports can be tricky but yours looks very clean. I think I just need some more breathing room between the support and the model so I can get a small tool in there.

ThorstenBr, 2024-10-03:
The trick for me was not to get in between the part and the support - but just between the support layers. So the lowest layer of the support mesh (making contact with the part) remained completely in tact, when it popped off:

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

Good luck! :)

k6lcm, 2024-10-03:
After doing some reading, I played around a bit with "Support Z Distance" and "Support Density" in Cura. Increasing the Support Z Distance to 0.2 gave it just enough gap between the model and the support that it was much easier to remove. Setting the support density up from 15% to 25% led to a smoother surface on the model underneath. You could probably play with these two settings to get it even smoother but I am happy with my results. Hopefully this is helpful to someone who is struggling with this issue. I think it is going to vary based on printer, slicer and material.

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

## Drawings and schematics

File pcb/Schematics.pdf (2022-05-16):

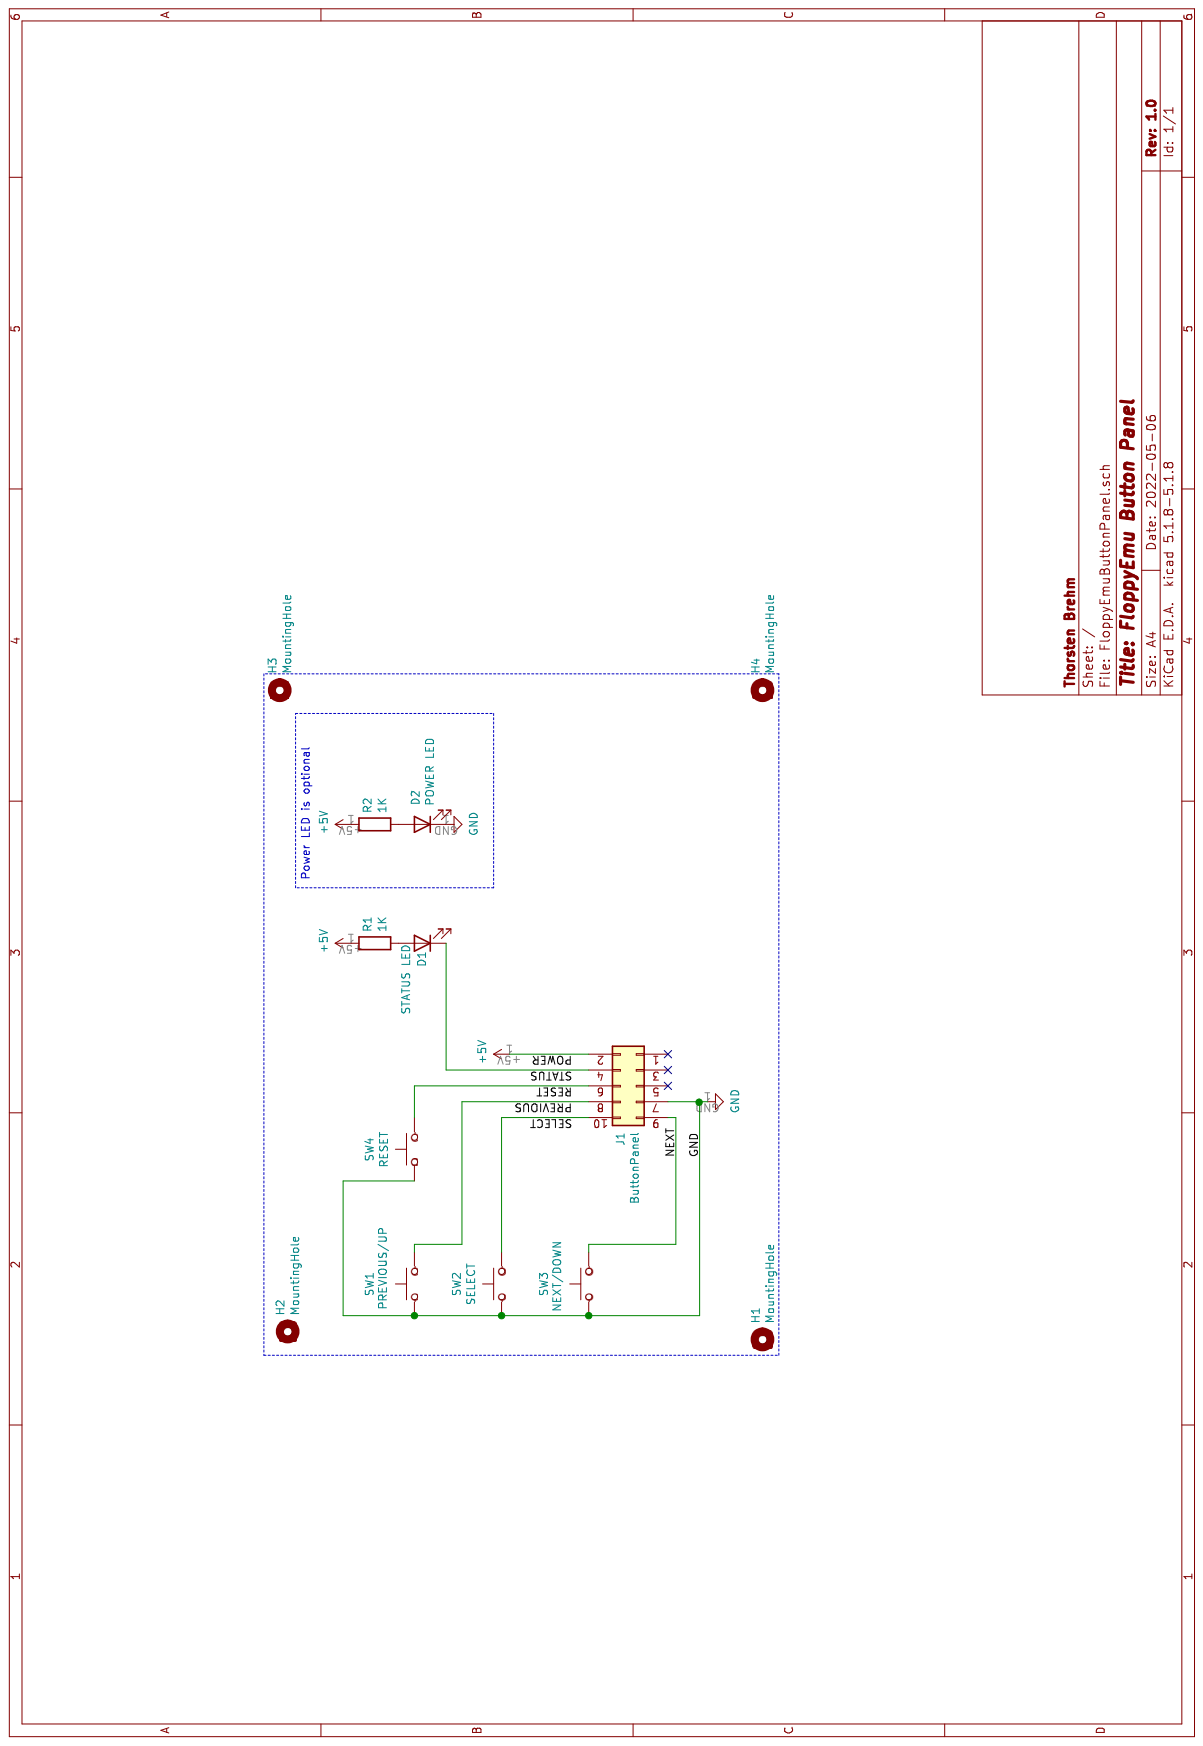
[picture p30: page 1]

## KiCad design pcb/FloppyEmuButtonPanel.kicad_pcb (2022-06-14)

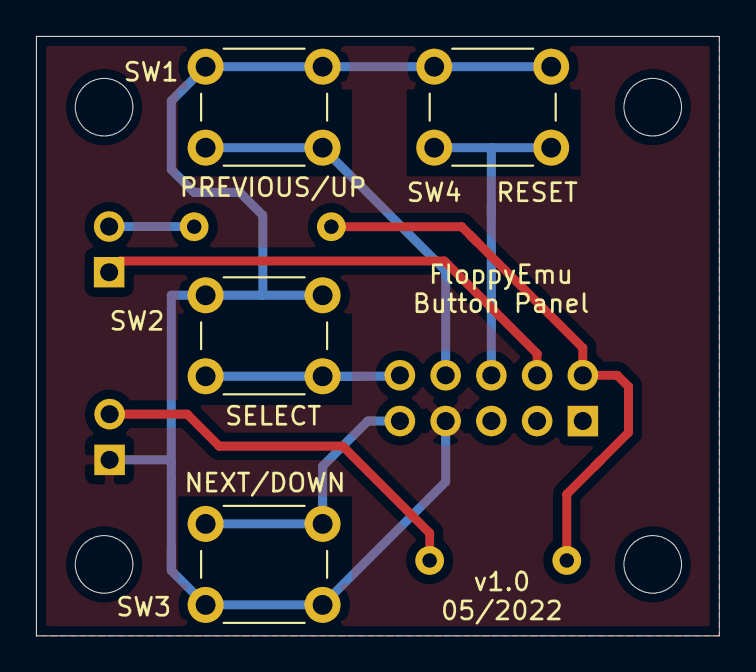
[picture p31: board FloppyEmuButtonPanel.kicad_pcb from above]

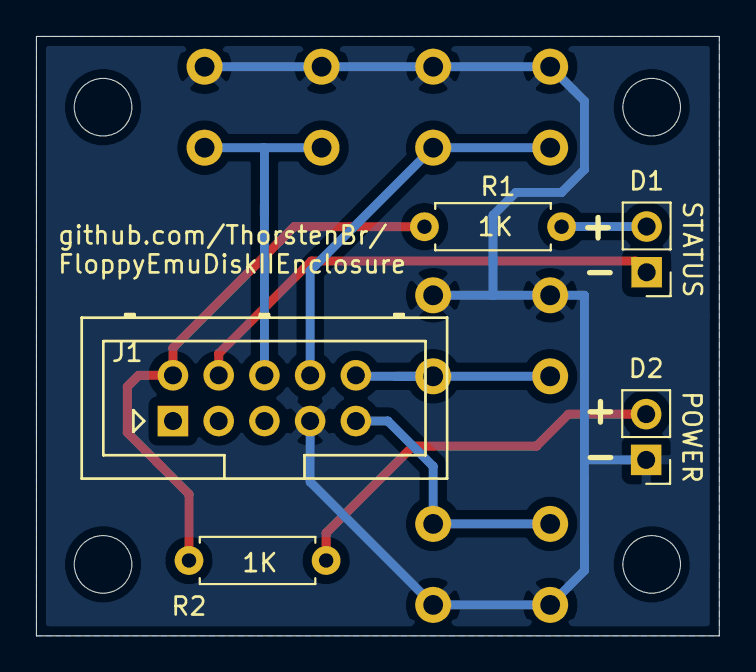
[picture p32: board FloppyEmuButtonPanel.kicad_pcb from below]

Board: 2 copper layers, 37.9 x 33.3 mm, 13 parts (5 on the bottom side), 9 nets.

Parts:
D1: STATUS; Pin_Header_Straight_1x02_Pitch2.54mm
D2: POWER; Pin_Header_Straight_1x02_Pitch2.54mm
H1, H2, H3, H4: MountingHole; MountingHole_3.2mm_M3
J1: ButtonPanelConnector; Box_Header_2x05x2.54mm_Straight
R1, R2: 1K; R_Axial_DIN0207_L6.3mm_D2.5mm_P7.62mm_Horizontal
SW1: PREVIOUS/UP; SW_PUSH_6mm_h5mm
SW2: SELECT; SW_PUSH_6mm_h5mm
SW3: NEXT/DOWN; SW_PUSH_6mm_h5mm
SW4: RESET; SW_PUSH_6mm_h5mm

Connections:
+5V: J1.2, R1.1, R2.1
/NEXT: J1.9, SW3.1
/PREVIOUS: J1.8, SW1.2
/RESET: J1.6, SW4.2
/SELECT: J1.10, SW2.2
/STATUS: D1.1, J1.4
GND: D2.1, J1.7, SW1.1, SW2.1, SW3.2, SW4.1
unnamed: D1.2, R1.2
unnamed: D2.2, R2.2

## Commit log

2022-05-15 Initial version of the main SCAD file.
    [main.scad]
2022-05-15 Added PCB schematics.
2022-05-16 Added KiCad schematics and PCB design for button panel.
    [FloppyEmuButtonPanel.kicad_pcb, FloppyEmuButtonPanel.sch]
2022-05-16 Updated front panel image to match current design.
2022-05-16 Update README.md
    Added push button specification
2022-05-16 Added OpenSCAD files.
    [baseLib.scad, buttons.scad, front.scad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]
2022-05-16 Improved element selection.
    [main.scad]
2022-05-17 PCB Update
    [FloppyEmuButtonPanel.kicad_pcb, FloppyEmuButtonPanel.sch]
2022-05-17 Corrected button panel (mounting points). Added Gerber files for PCB.
    [FloppyEmuButtonPanel-B_Cu.gbr, FloppyEmuButtonPanel-B_Mask.gbr, FloppyEmuButtonPanel-B_Paste.gbr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]
2022-05-17 Added print instructions.
2022-05-17 Moved cable strain-relief from rear panel to top shell which provides much better stability. The strain-relief is angled, so the bracket can still be attached and screwed when the top shell and base 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
    [buttons.scad, main.scad, rear.scad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]
2022-05-17 Added STL files for the first version of the small-sized FloppyEmu Disk II enclosure.
    [DiskII_BasePlate_Small.stl, DiskII_ButtonsBrackets_Small.stl, DiskII_FrontPanel_Small.stl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]
2022-05-17 Updated image showing 3D print preview.
2022-05-18 Improved description of required material.
2022-05-18 Prepared support for jumbo display (not tested yet).
    [main.scad]
2022-05-22 Added enclosure for Floppy Emu's DB-19 plug adapter.
    [baseLib.scad, disk_II.scad, plug_adapter.scad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]
2022-05-22 Added description of power rails to adapter photo.
2022-06-14 Minor PCB design update.
    [FloppyEmuButtonPanel-B_Cu.gbr, FloppyEmuButtonPanel-B_Mask.gbr, FloppyEmuButtonPanel-B_Paste.gbr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]
2023-09-22 Several minor improvements: - Changed "reset button" to a small round button, while the three control buttons keep their larger/rectangular shape. The reset button is barely needed. The round shape a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
    [DiskII_BasePlate_Small.stl, DiskII_ButtonsBrackets_Small.stl, DiskII_FrontPanel_Small.stl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]
